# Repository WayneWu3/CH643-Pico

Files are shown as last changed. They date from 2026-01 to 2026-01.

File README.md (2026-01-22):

# CH643-Pico

## Introduction
The ch643-pico is a development board based on the WCH CH643Q 32-bit RISC-V MCU. It provides a compact and breadboard-friendly platform for USB Type-C and Power Delivery applications.

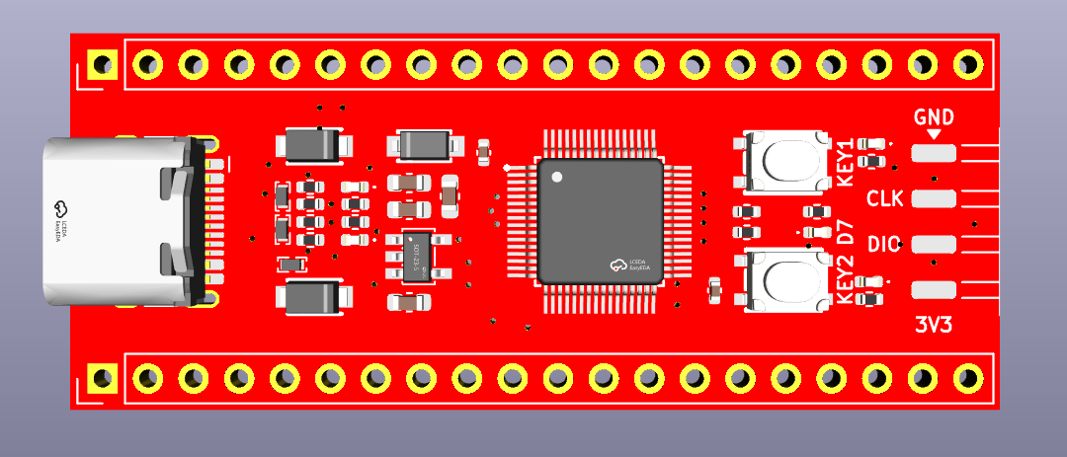
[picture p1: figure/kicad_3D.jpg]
CH643 Custom Board


## Hardware Resources
*   **MCU**: WCH CH643Q featuring the QingKe-V4C RISC-V core.
*   **Interface**: USB Type-C port for power delivery and data communication.
*   **Power**: Dual power input support with 3.3V regulated output.
*   **Control**: Two user buttons and status LEDs for power and communication monitoring.
*   **Debug**: Dedicated pin headers for UART and SWD interfaces.

## Pin Definitions
| Pin | Label  | Function |
| :-- | :----- | :--- |
| 1 | 3.3V | 3.3V Power Output |
| 2 | 3.3V | 3.3V Power Output |
| 3 | GND | GND |
| 4 | PA23 | TIM2_CH3N |
| 5 | PA1 | TIM2_CH2/ADC_IN1 |
| 6 | PA2 | USART2_TX/TIM2_CH3/ADC_IN2 |
| 7 | PA3 | USART2_RX/TIM2_CH4/ADC_IN3 |
| 8 | GND | GND |
| 9 | PA5 | SPI0_SCK/ADC_IN5 |
| 10  | PA6 | SPI0_MISO/TIM3_CH1/ADC_IN6 |
| 11  | PA7 | SPI0_MOSI/TIM3_CH2/ADC_IN7 |
| 12  | PB0 | USART4_TX/ADC_IN8 |
| 13  | PB1 | USART4_RX/ADC_IN9 |
| 14  | PB2 | TIM1_CH2N |
| 15  | PB3 | TIM1_CH3N |
| 16  | PB4 | GPIO |
| 17  | PB6 | TIM1_CH1N/USART3_CTS |
| 18  | PB7 | TIM1_CH2N/USART3_RTS |
| 19  | PB8 | TIM1_CH3N |
| 20  | PB9 | TIM1_CH1/MCO |
| 21  | EXT_5V | 5V Power Input |
| 22  | EXT_5V | 5V Power Input |
| 23  | GND | GND |
| 24  | 3.3V | 3.3V Power Output |
| 25  | EXT_5V | 5V Power Input |
| 26  | PA21 | TIM2_CH1N |
| 27  | PA20 | TIM2_BK |
| 28  | GND | GND |
| 29  | PA19 | TIM2_ETR |
| 30  | PA15 | GPIO |
| 31  | 3.3V | 3.3V Power Output |
| 32  | PA11 | I2C_SDA |
| 33  | GND | GND |
| 34  | PA10 | I2C_SCL |
| 35  | PA8 | USART4_RTS |
| 36  | PB15 | USART4_CTS |
| 37  | PB23 | GPIO |
| 38  | GND | GND |
| 39  | PB21 | GPIO |
| 40  | PB14 | GPIO |

## Onboard Peripherals
| Component | Pin  | Logic |
| :--- | :--- | :--- |
| KEY1 | PB12 | Active Low  |
| KEY2 | PB16 | Active Low  |
| LED | PB17 | Active Low |

## Functional Features
*   **Power Path**: Integrated Schottky diodes protect the circuit when using both USB and external power sources.
*   **ESD Protection**: USB data and configuration channel lines are equipped with protection arrays to ensure hardware durability.
*   **Logic Level**: All I/O signals are 3.3V compatible.

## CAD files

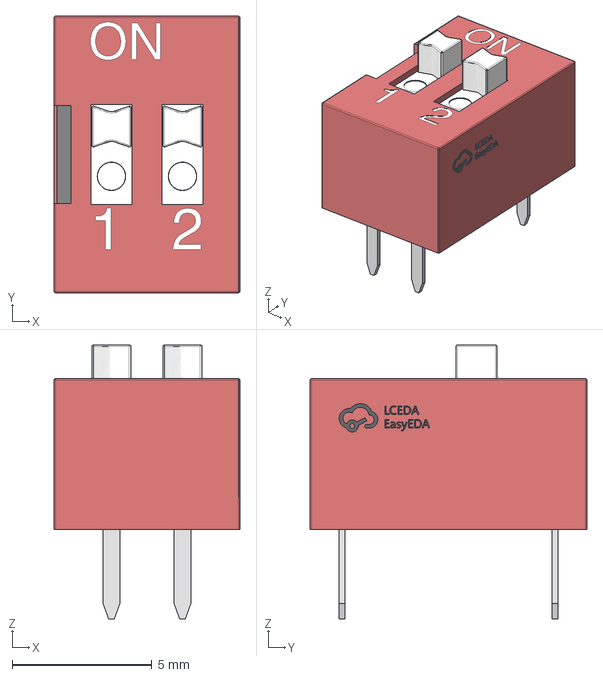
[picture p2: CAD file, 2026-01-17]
EASYEDA_MODELS/SW-TH_DS-02.step
6.64 x 9.90 x 9.80 mm

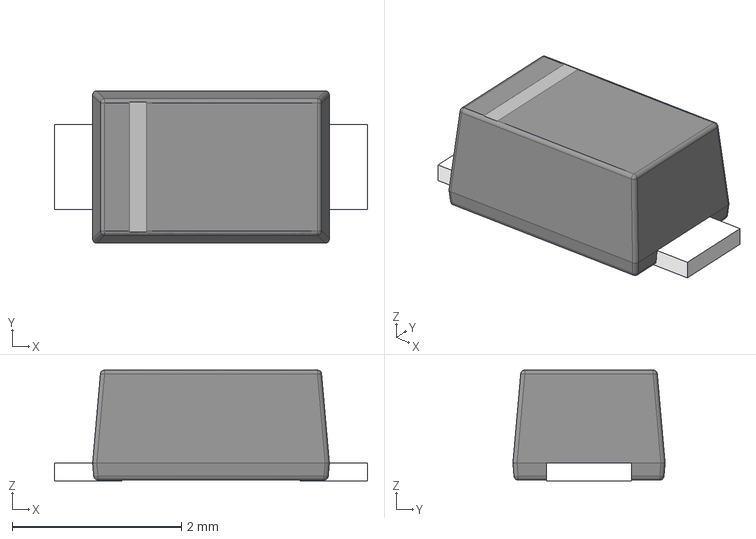
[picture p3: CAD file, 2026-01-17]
EASYEDA_MODELS/SOD-123FL_L2.8-W1.8-LS3.7-RD-1.step
3.70 x 1.80 x 1.31 mm

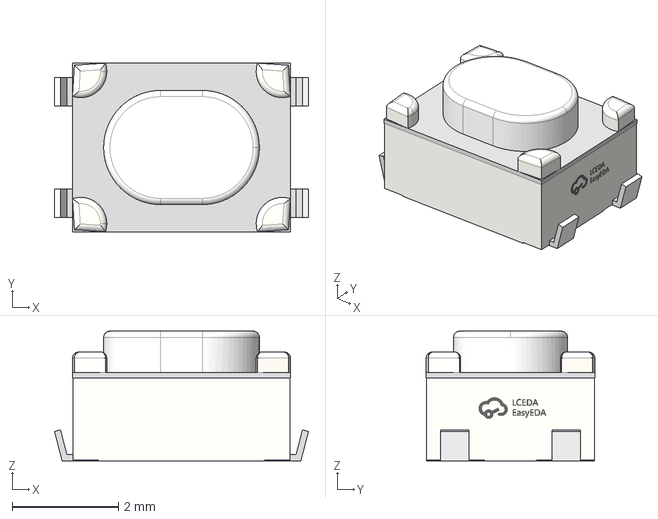
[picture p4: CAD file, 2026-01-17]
EASYEDA_MODELS/SW-SMD_4P-L4.2-W3.3-H2.5-P2.15-LS4.6.step
4.78 x 3.18 x 2.44 mm

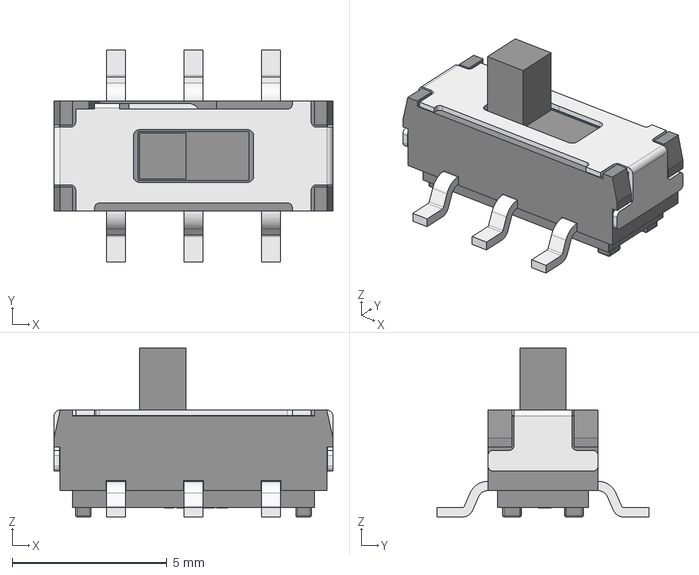
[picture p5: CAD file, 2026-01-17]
EASYEDA_MODELS/SW-SMD_MST22D18G2.step
9.00 x 6.85 x 5.45 mm

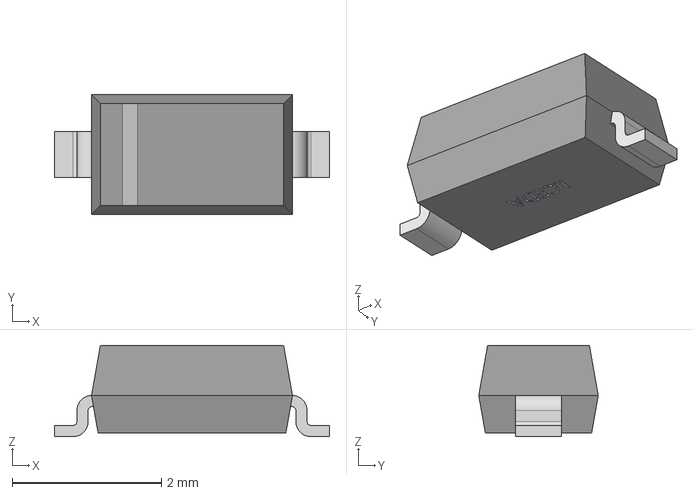
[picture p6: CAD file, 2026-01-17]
EASYEDA_MODELS/SOD-123_L2.8-W1.8-LS3.7-RD.step
3.68 x 1.60 x 1.22 mm

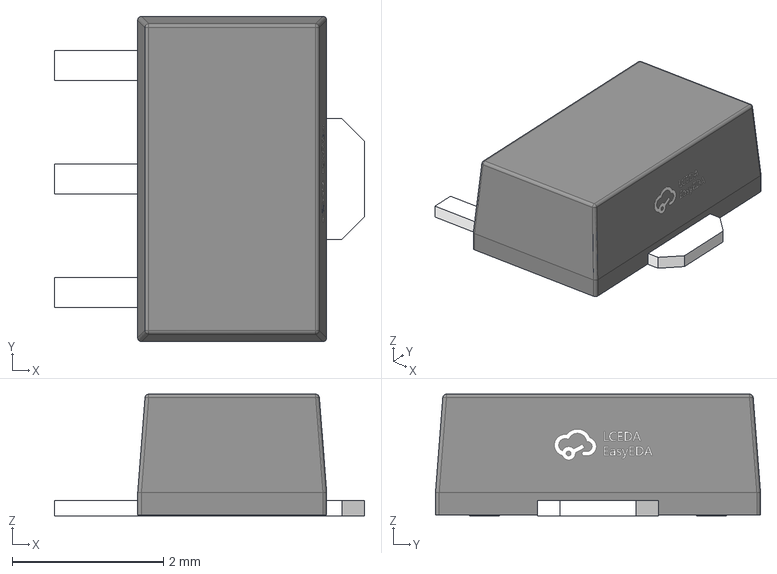
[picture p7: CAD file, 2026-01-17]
EASYEDA_MODELS/SOT-89-3_L4.3-W2.5-H1.6-LS4.1-P1.50.step
4.10 x 4.30 x 1.61 mm

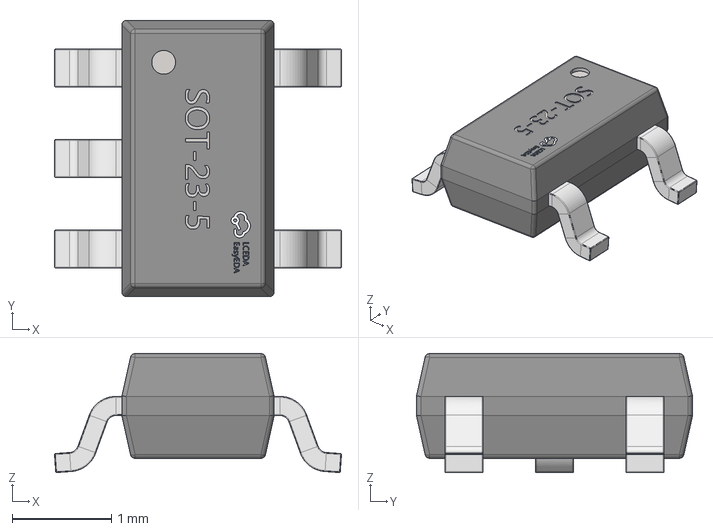
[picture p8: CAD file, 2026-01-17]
EASYEDA_MODELS/SOT-23-5_L2.9-W1.6-H1.1-LS2.8-P0.95.step
2.90 x 2.79 x 1.20 mm

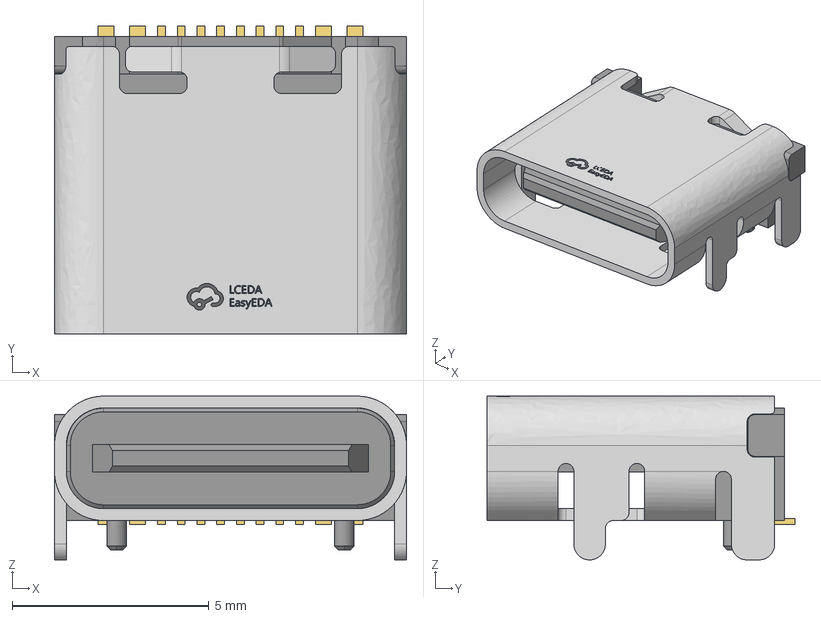
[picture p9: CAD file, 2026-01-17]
EASYEDA_MODELS/USB-C-SMD_TYPE-C-16P-1.step
8.94 x 7.81 x 4.16 mm

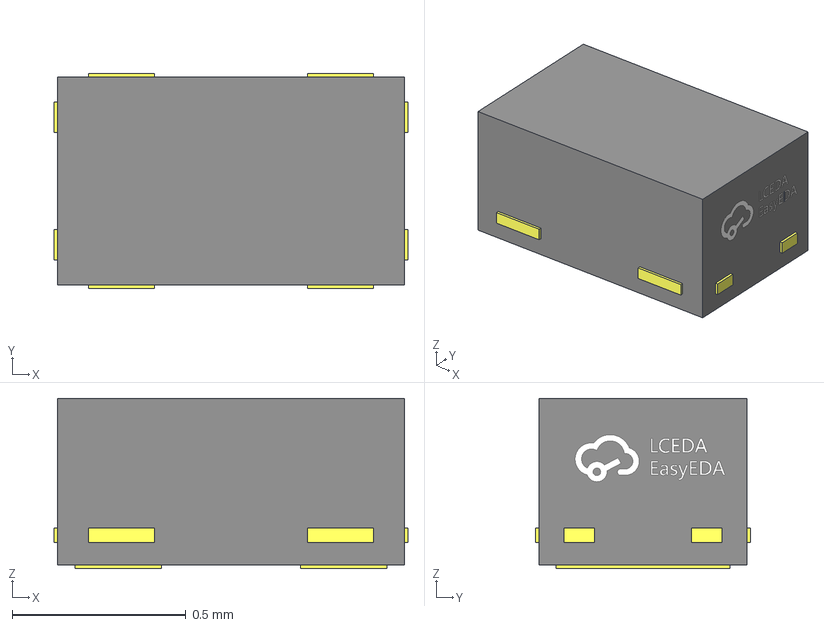
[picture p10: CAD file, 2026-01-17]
EASYEDA_MODELS/DFN1006-2L-BI.step
1.02 x 0.62 x 0.49 mm

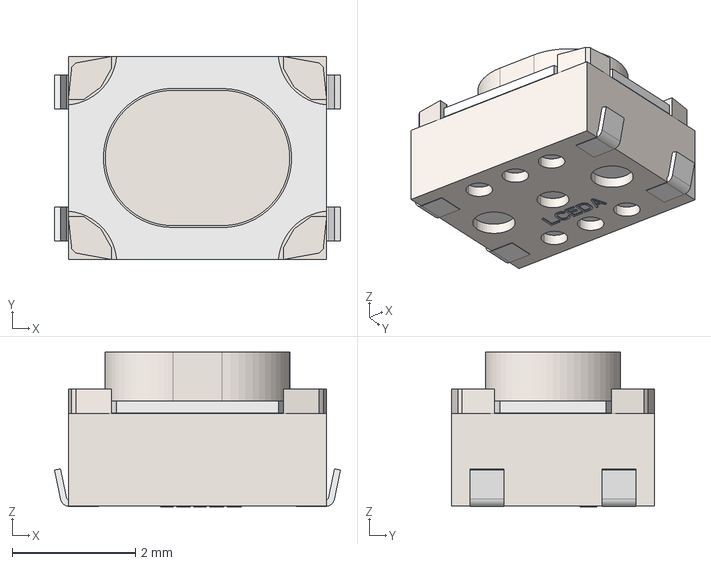
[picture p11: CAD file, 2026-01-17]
EASYEDA_MODELS/SW-SMD_4P-L4.2-W3.3-P2.15-LS4.7.step
4.65 x 3.30 x 2.52 mm

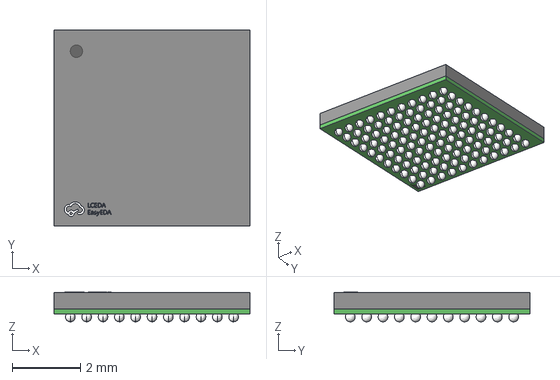
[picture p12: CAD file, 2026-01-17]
EASYEDA_MODELS/CSFBGA-121_L6.0-W6.0-R11-C11-P0.50-TL.step
5.74 x 5.74 x 0.871 mm

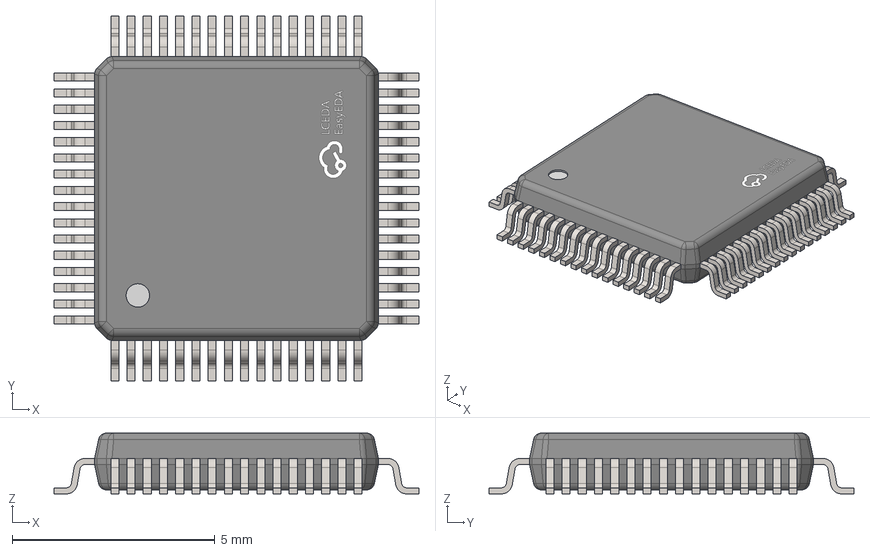
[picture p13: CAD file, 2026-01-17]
EASYEDA_MODELS/LQFP-64_L7.0-W7.0-P0.40-LS9.0-BL.step
9.00 x 9.00 x 1.50 mm

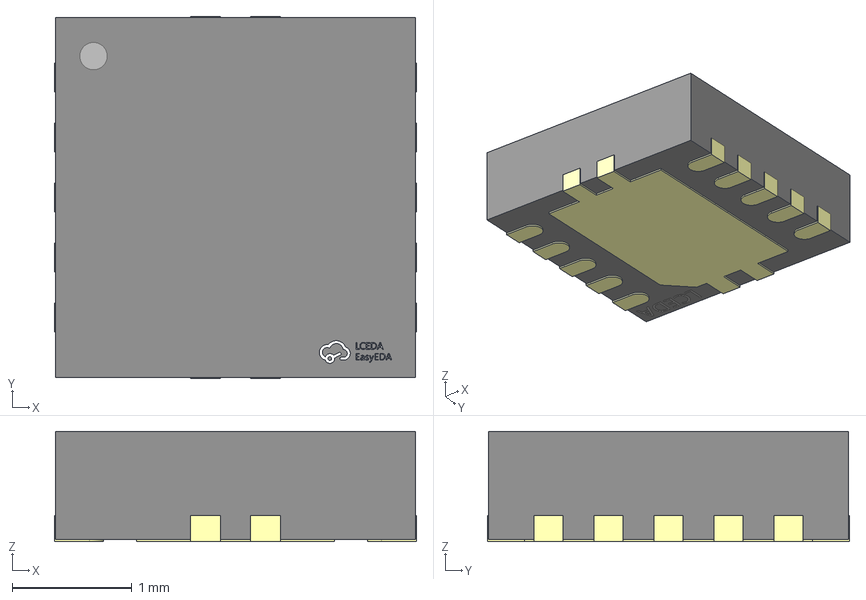
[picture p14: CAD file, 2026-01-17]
EASYEDA_MODELS/VSON-10_L3.0-W3.0-P0.50-BL-EP1.65.step
3.02 x 3.02 x 0.921 mm

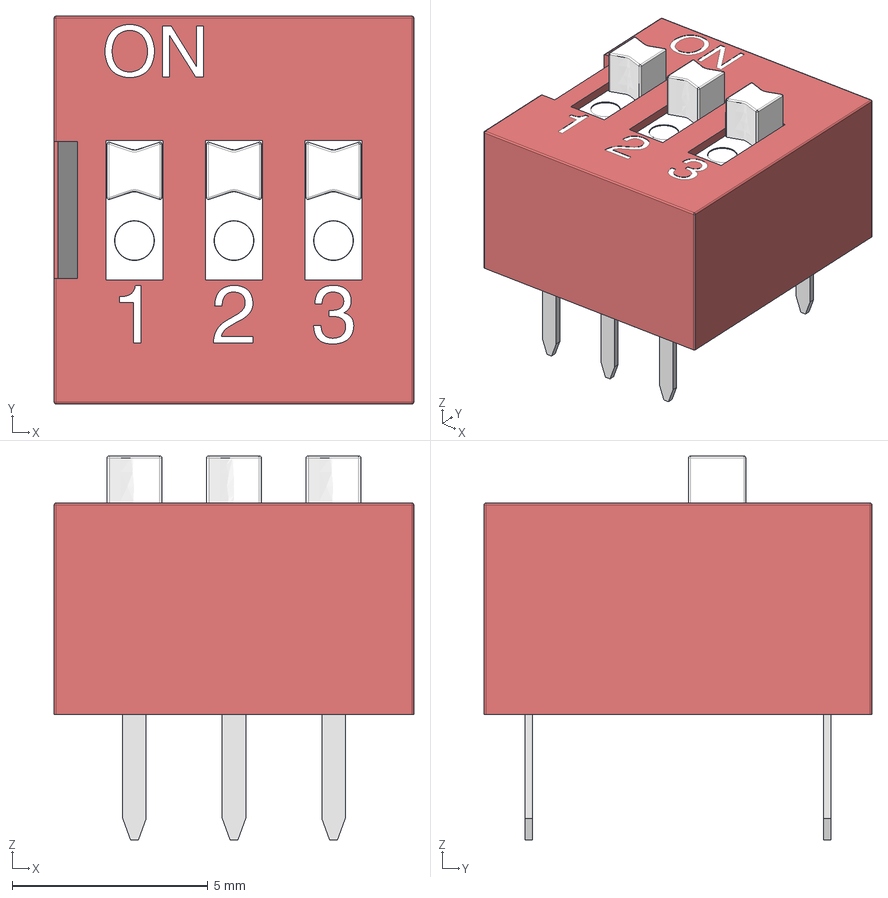
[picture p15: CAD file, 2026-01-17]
EASYEDA_MODELS/SW-TH_L9.1-W9.9-H5.4-P2.54-R.step
9.18 x 9.90 x 9.80 mm

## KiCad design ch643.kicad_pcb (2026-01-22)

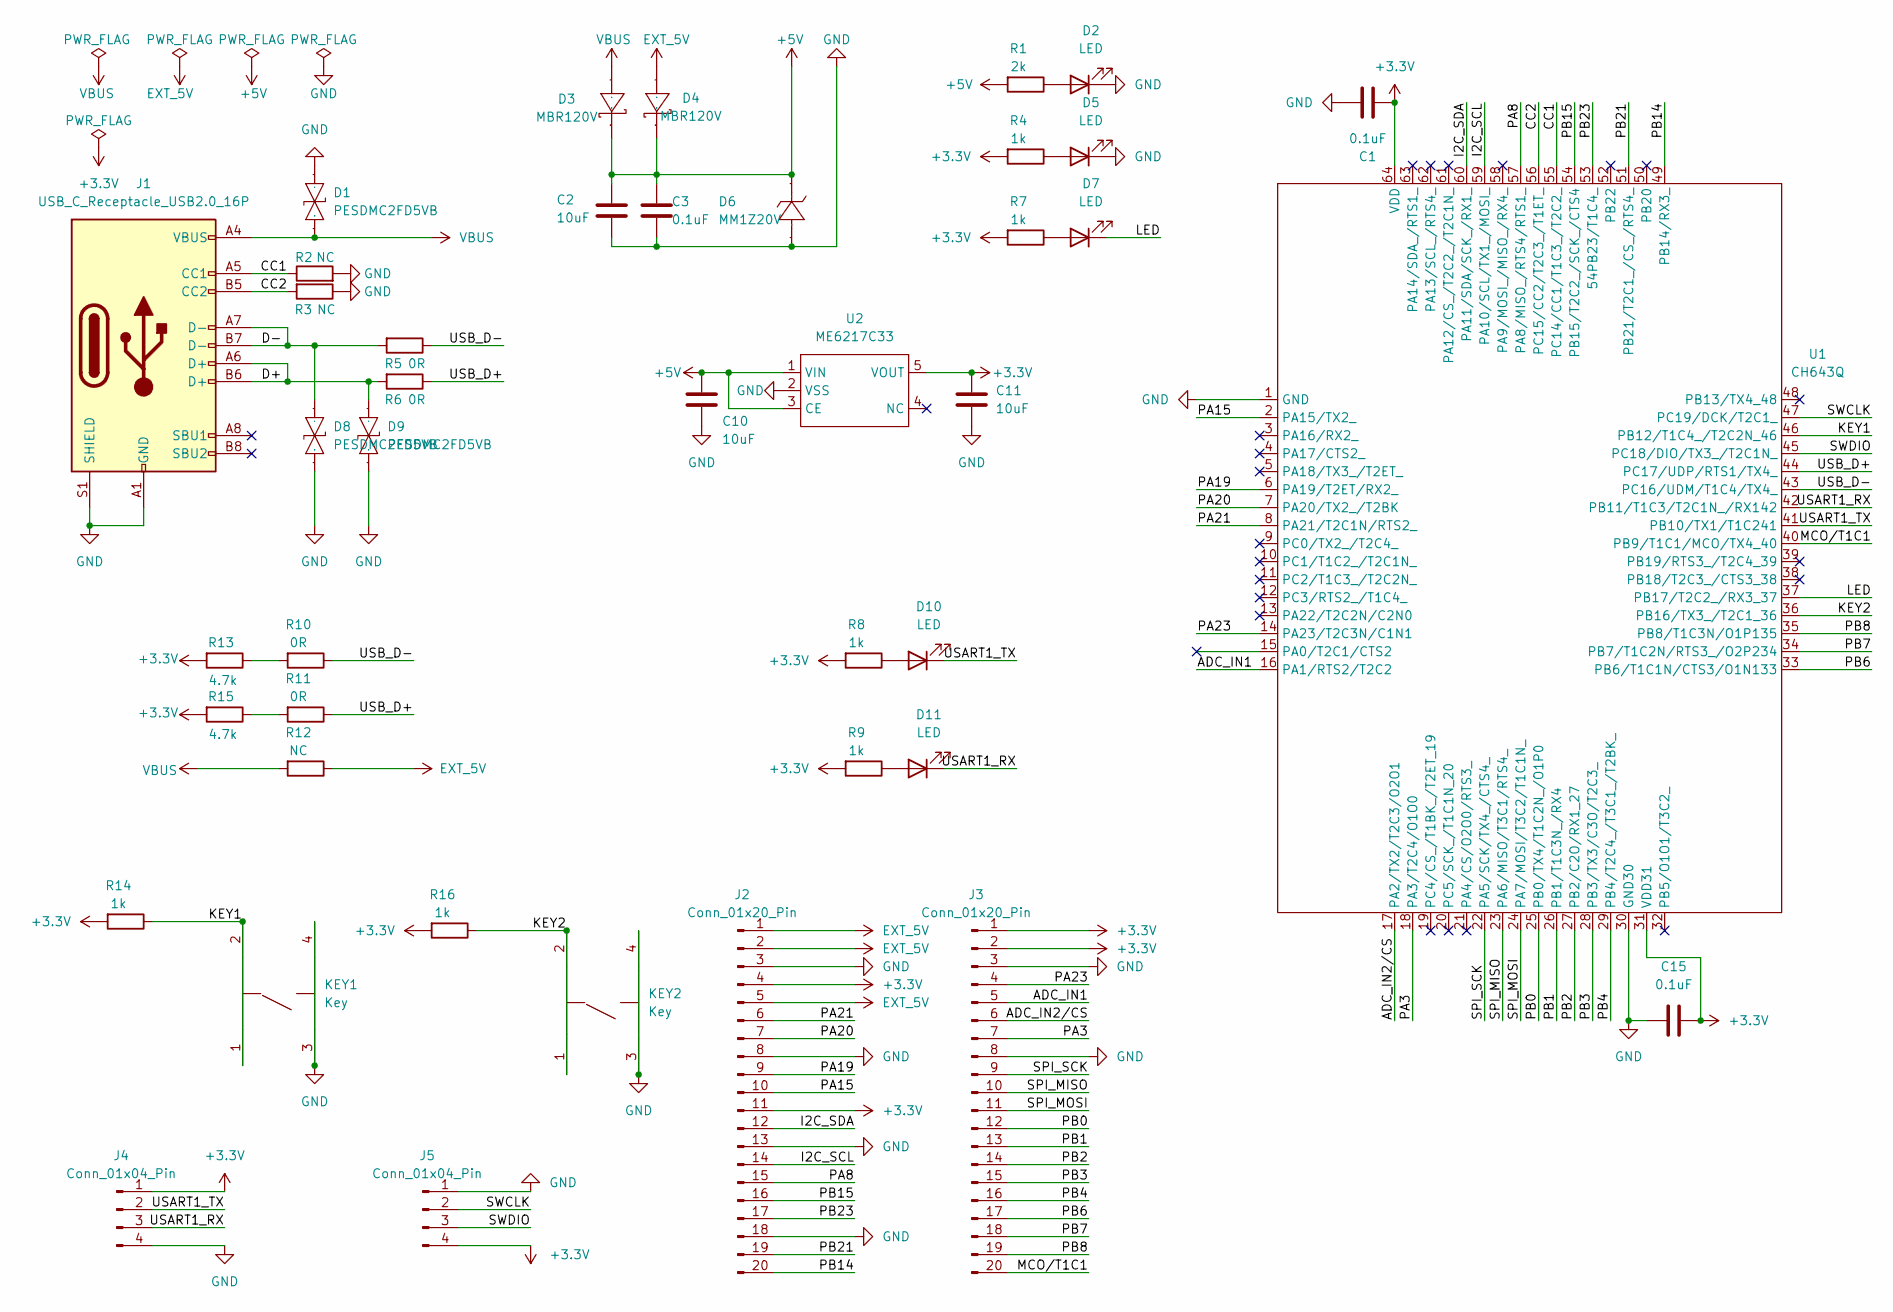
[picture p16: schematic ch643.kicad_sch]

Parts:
C1, C15: 0.1uF; C_0402_1005Metric
C2, C10, C11: 10uF; C_0603_1608Metric
C3: 0.1uF; C_0603_1608Metric
D1, D8, D9: PESDMC2FD5VB; DFN1006-2L-BI; Manufacturer Part PESDMC2FD5VB; LCSC Part Name 双向ESD
D2, D5, D7, D10, D11: LED; LED_0402_1005Metric
D3, D4: MBR120V; SOD-123F_L2.8-W1.8-LS3.7-RD; Manufacturer Part MBR120VLSFT1G; LCSC Part Name 电压:20V 电流:1A
D6: MM1Z20V; SOD-123_L2.8-W1.8-LS3.7-RD; Manufacturer Part MM1Z20V; LCSC Part Name MM1Z20V
J1: USB_C_Receptacle_USB2.0_16P; USB_C_Receptacle_HCTL_HC-TYPE-C-16P-01A
J2, J3: Conn_01x20_Pin; PinHeader_1x20_P2.54mm_Vertical
J4, J5: Conn_01x04_Pin; Harwin_M20-89004xx_1x04_P2.54mm_Horizontal
KEY1, KEY2: Key; SW-SMD_4P-L4.2-W3.3-P2.15-LS4.6; Manufacturer Part TSA016A2526A; LCSC Part Name 3.2*4.2*2.5H-J 260gf 白钮翘脚
R1: 2k; R_0402_1005Metric
R2, R3, R12: NC; R_0402_1005Metric
R4, R7, R8, R9, R14, R16: 1k; R_0402_1005Metric
R5, R6, R10, R11: 0R; R_0402_1005Metric
R13, R15: 4.7k; R_0402_1005Metric
U1: CH643Q; LQFP-64_L7.0-W7.0-P0.40-LS9.2-BL; Manufacturer Part CH643Q; LCSC Part Name RGB显示驱动工业级微控制器
U2: ME6217C33; SOT-23-5_L3.0-W1.7-P0.95-LS2.8-BR; Manufacturer Part ME6217C33M5G; LCSC Part Name 输入7V 输出3.3V 800mA

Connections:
+3.3V: C1.1, C11.1, C15.1, J2.4, J2.11, J3.1, J3.2, J4.1, J5.4, R4.2, R7.2, R8.2, R9.2, R13.2, R14.2, R15.2, R16.2, U1.31 (VDD31), U1.64 (VDD), U2.5 (VOUT)
+5V: C2.1, C3.1, C10.1, D3.1 (K), D4.1 (K), D6.1 (K), R1.2, U2.1 (VIN), U2.3 (CE)
/ADC_IN1: J3.5, U1.16 (PA1/RTS2/T2C2)
/ADC_IN2/CS: J3.6, U1.17 (PA2/TX2/T2C3/O2O1)
/CC1: J1.A5 (CC1), R2.1, U1.55 (PC14/CC1/T1C3_/T2C2_)
/CC2: J1.B5 (CC2), R3.2, U1.56 (PC15/CC2/T2C3_/T1ET_)
/D+: D9.2, J1.A6 (D+), J1.B6 (D+), R6.2
/D-: D8.2, J1.A7 (D-), J1.B7 (D-), R5.2
/I2C_SCL: J2.14, U1.59 (PA10/SCL/TX1_/MOSI_)
/I2C_SDA: J2.12, U1.60 (PA11/SDA/SCK_/RX1_)
/KEY1: KEY1.1, KEY1.2, R14.1, U1.46 (PB12/T1C4_/T2C2N_46)
/KEY2: KEY2.1, KEY2.2, R16.1, U1.36 (PB16/TX3_/T2C1_36)
/LED: D7.1 (K), U1.37 (PB17/T2C2_/RX3_37)
/MCO/T1C1: J3.20, U1.40 (PB9/T1C1/MCO/TX4_40)
/PA3: J3.7, U1.18 (PA3/T2C4/O1O0)
/PA8: J2.15, U1.57 (PA8/MISO_/RTS4/RTS1_)
/PA15: J2.10, U1.2 (PA15/TX2_)
/PA19: J2.9, U1.6 (PA19/T2ET/RX2_)
/PA20: J2.7, U1.7 (PA20/TX2_/T2BK)
/PA21: J2.6, U1.8 (PA21/T2C1N/RTS2_)
/PA23: J3.4, U1.14 (PA23/T2C3N/C1N1)
/PB0: J3.12, U1.25 (PB0/TX4/T1C2N_/O1P0)
/PB1: J3.13, U1.26 (PB1/T1C3N_/RX4)
/PB2: J3.14, U1.27 (PB2/C2O/RX1_27)
/PB3: J3.15, U1.28 (PB3/TX3/C3O/T2C3_)
/PB4: J3.16, U1.29 (PB4/T2C4_/T3C1_/T2BK_)
/PB6: J3.17, U1.33 (PB6/T1C1N/CTS3/O1N133)
/PB7: J3.18, U1.34 (PB7/T1C2N/RTS3_/O2P234)
/PB8: J3.19, U1.35 (PB8/T1C3N/O1P135)
/PB14: J2.20, U1.49 (PB14/RX3_)
/PB15: J2.16, U1.54 (PB15/T2C2_/SCK_/CTS4)
/PB21: J2.19, U1.51 (PB21/T2C1_/CS_/RTS4_)
/PB23: J2.17, U1.53 (54PB23/T1C4_)
/SPI_MISO: J3.10, U1.23 (PA6/MISO/T3C1/RTS4_)
/SPI_MOSI: J3.11, U1.24 (PA7/MOSI/T3C2/T1C1N_)
/SPI_SCK: J3.9, U1.22 (PA5/SCK/TX4_/CTS4_)
/SWCLK: J5.2, U1.47 (PC19/DCK/T2C1_)
/SWDIO: J5.3, U1.45 (PC18/DIO/TX3_/T2C1N_)
/USART1_RX: D11.1 (K), J4.3, U1.42 (PB11/T1C3/T2C1N_/RX142)
/USART1_TX: D10.1 (K), J4.2, U1.41 (PB10/TX1/T1C241)
/USB_D+: R6.1, R11.1, U1.44 (PC17/UDP/RTS1/TX4_)
/USB_D-: R5.1, R10.1, U1.43 (PC16/UDM/T1C4/TX4_)
EXT_5V: D4.2 (A), J2.1, J2.2, J2.5, R12.1
GND: C1.2, C2.2, C3.2, C10.2, C11.2, C15.2, D1.2, D2.1 (K), D5.1 (K), D6.2 (A), D8.1, D9.1, J1.A1 (GND), J1.A12 (GND), J1.B1 (GND), J1.B12 (GND), J1.S1 (SHIELD), J2.3, J2.8, J2.13, J2.18, J3.3, J3.8, J4.4, J5.1, KEY1.3, KEY1.4, KEY2.3, KEY2.4, R2.2, R3.1, U1.1 (GND), U1.30 (GND30), U2.2 (VSS)
unnamed: D2.2 (A), R1.1
unnamed: D5.2 (A), R4.1
unnamed: D7.2 (A), R7.1
unnamed: D10.2 (A), R8.1
unnamed: D11.2 (A), R9.1
unnamed: R10.2, R13.1
unnamed: R11.2, R15.1
VBUS: D1.1, D3.2 (A), J1.A4 (VBUS), J1.A9 (VBUS), J1.B4 (VBUS), J1.B9 (VBUS), R12.2

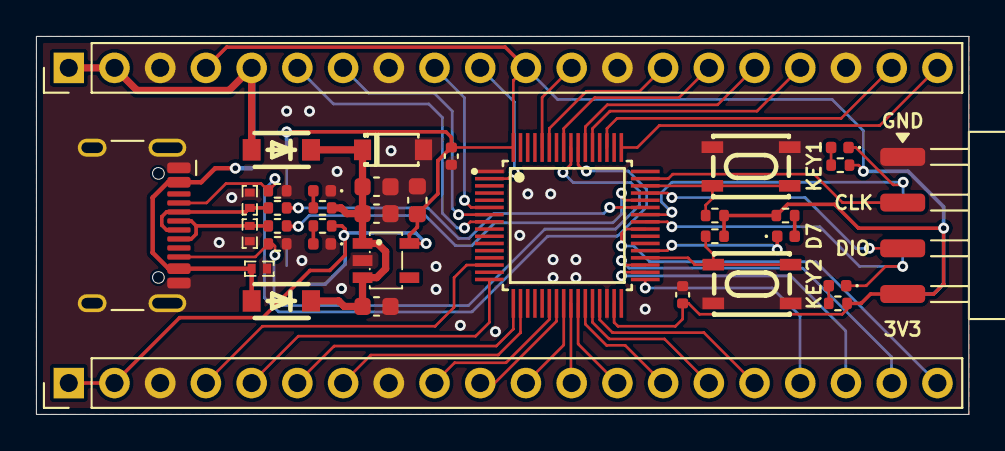
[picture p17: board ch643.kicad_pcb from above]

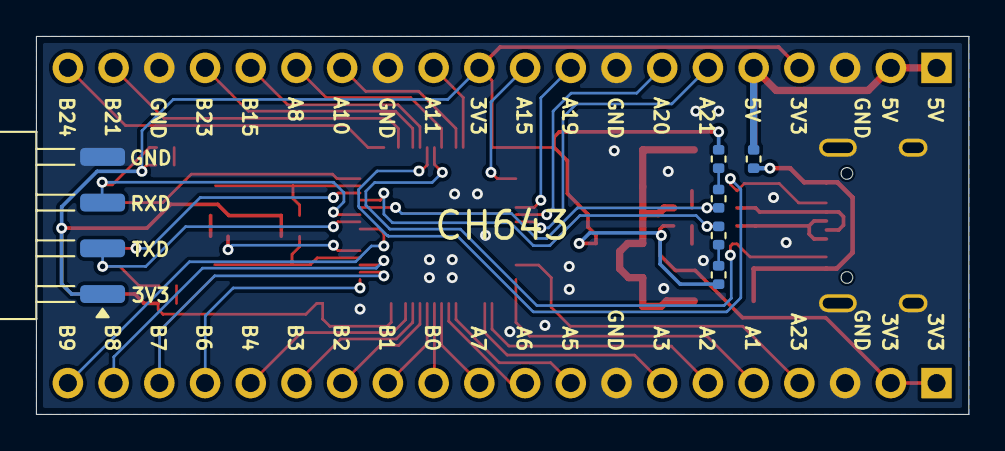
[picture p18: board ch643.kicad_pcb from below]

Board: 2 copper layers, 51.8 x 21.0 mm, 42 parts (6 on the bottom side), 52 nets.

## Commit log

2026-01-17 CH643-Pico in kicad
    [CSFBGA-121_L6.0-W6.0-R11-C11-P0.50-TL.step, DFN1006-2L-BI.step, LQFP-64_L7.0-W7.0-P0.40-LS9.0-BL.step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]
2026-01-22 feat: add 3D display
    [ch643.kicad_pcb]
2026-01-22 docs: add 3D render of CH643 Pico
